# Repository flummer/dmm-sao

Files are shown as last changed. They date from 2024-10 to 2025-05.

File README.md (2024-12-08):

# SAO Digital Multimeter

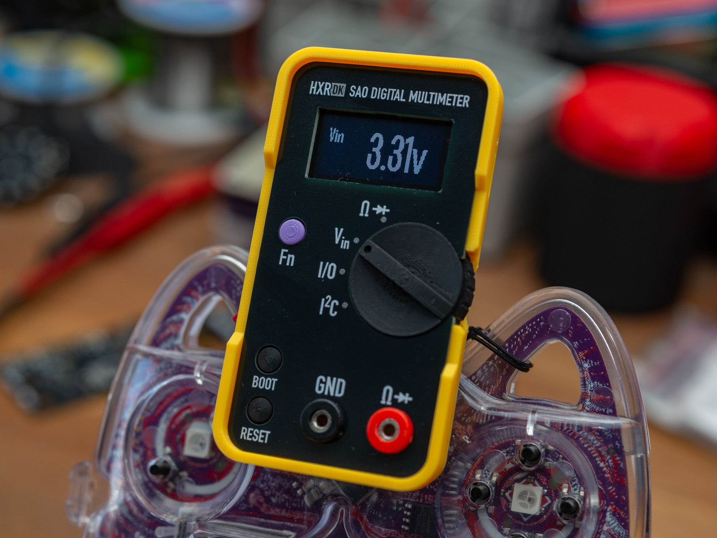
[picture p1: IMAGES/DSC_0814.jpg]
SAO Digital Multimeter


Additional documentation and build log can be found on the [hackaday.io project page for the SAO Digital Multimeter](https://hackaday.io/project/198892-sao-digital-multimeter)

## Features

- Resistance measurement and LED test (including continuity test with a buzzer)
- SAO Input voltage measurement
- SAO GPIO voltage measurement
- I2C info (WIP)

## Firmware

This is designed to run CircuitPython and there is [a custom build](https://github.com/flummer/circuitpython/tree/hxr-sao-dmm) with the needed libraries included, and meaningful pin names for easier development.

A binary build of this is included under `firmware/firmware.uf2` and the application code (`code.py`) and resource files are also in the `firmware` folder.

### Initial programming or CircuitPython updating

- Connect the SAO DMM to a computer usig a USB-C cable and hold down the `Boot` button, when pressing the `Reset` button.
- A new drive should show up called `RPI-RP2`, and you simply copy the `firmware.uf2` file to this drive.
- When the copy is done, the device will disconnect and reboot.
- A new drive will show up named `CIRCUITPY`, and here you need to copy the remaining files in the `firmware` folder to the root folder of the `CIRCUITPY` device.
- The device will not disconnect, but will do one or more reboots, and after that, you are done.

During this, you might be asked or be blocked by your operating system, as sometimes you will need to verify access to new, unknown devices.

## Case and other 3D printed parts

The case and all the button caps, the main knob, and internal spacers to make sure everything sits correctly are designed to be 3D printed with a regular consumer printer. They have been tweaked to be printable with a 0.4mm nozzle, but using a smaller one (eg. 0.2mm) will allow you to use thinner layers, at least in some places, to get a smoother top finnish (top of main knob and top of button caps really benefit from that).

There are also files for a set of 3D printable probes, that are designed to be assembled without any tools, sandwitched around a thin probe wire soldered to a P100-B1 pogo pin for the tip.

There is a `.3mf` file in the `case` folder with a project for BambuLab printers, including 5 plates, one for each color needed.

## Designed in KiCad v8.99 (nightly)

To open the project, you will need to install a recent nightly build (og v9 or newer when released), KiCad v8 or earlier won't open this design directly.

[Electronics schematics as a PDF file](https://github.com/flummer/dmm-sao/blob/main/DMM%20SAO%20Schematics.pdf) is also included for reference.

## License

The hardware design (both electronics and 3D designs) of the `main` branch of this repository is released under the following license:

* the "Creative Commons Attribution-ShareAlike 4.0 International License"
  (CC BY-SA 4.0) full text of this license is included in the LICENSE file
  and a copy can also be found at
  [http://creativecommons.org/licenses/by-sa/4.0/](http://creativecommons.org/licenses/by-sa/4.0/)

The CircuitPython firmware (including the python application code) is released under the MIT license with smaller dependencies under other licenses as detailed in [its LICENSE](https://github.com/flummer/circuitpython/blob/hxr-sao-dmm/LICENSE) and [LICENSE_MicroPython](https://github.com/flummer/circuitpython/blob/hxr-sao-dmm/LICENSE_MicroPython) files.

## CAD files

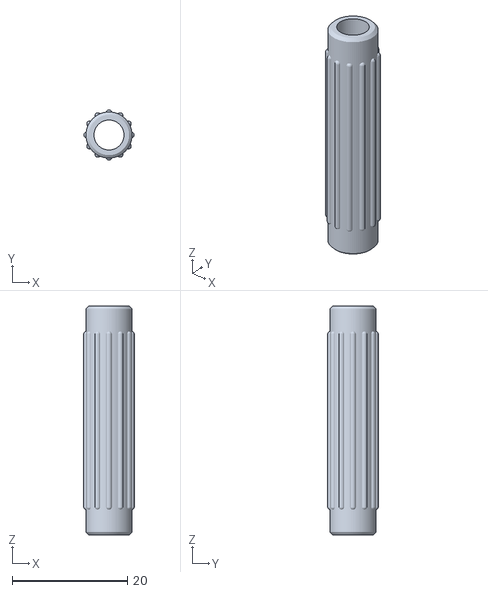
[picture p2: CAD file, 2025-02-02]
case/probe_middle_sleeve_alternative.stl
8.79 x 8.79 x 39.8

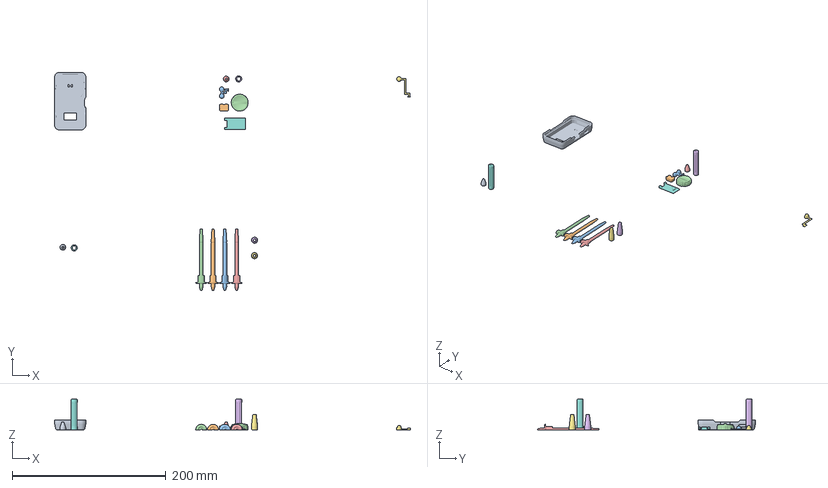
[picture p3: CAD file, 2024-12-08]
case/all_0.4mm_hotend_5_plates_single.3mf
463.8 x 284.3 x 39.8 mm
case_simple.stl
spacer_2.0.stl
buttons_boot_reset_hold_2.0.stl
knob_notches.stl
probe_tip_sleeve.stl x 2
probe_middle_sleeve.stl x 2
button_fn_hold_2.0.stl
probe_half.stl x 4
probe_top_sleeve.stl x 2
screen_support.stl

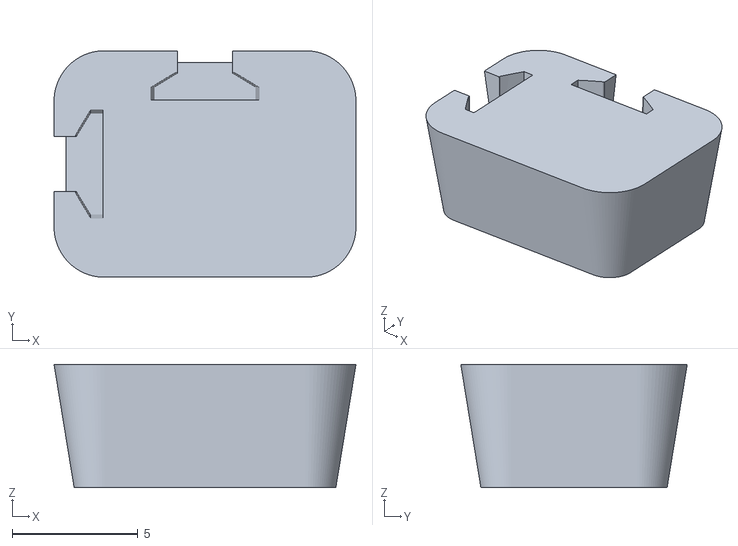
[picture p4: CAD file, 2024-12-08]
case/spacer_2.0.stl
12.0 x 9.00 x 4.90

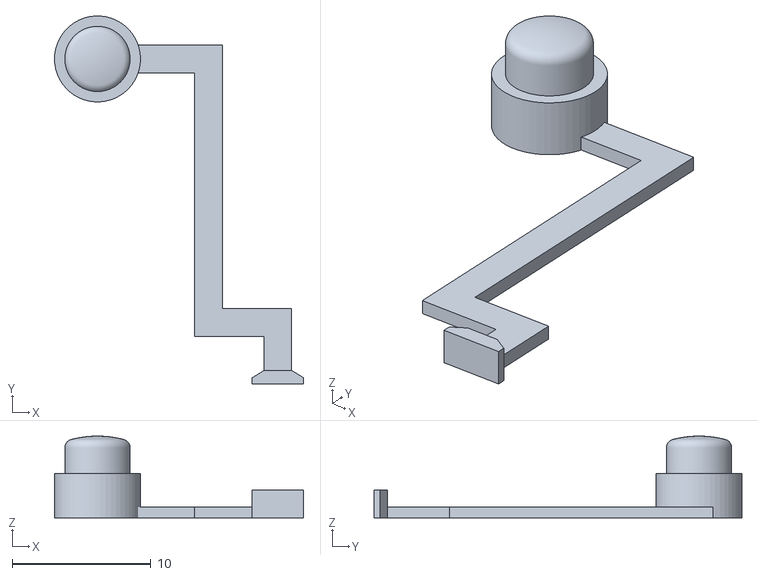
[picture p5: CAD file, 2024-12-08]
case/button_fn_hold_1.5.stl
18.0 x 26.5 x 5.90

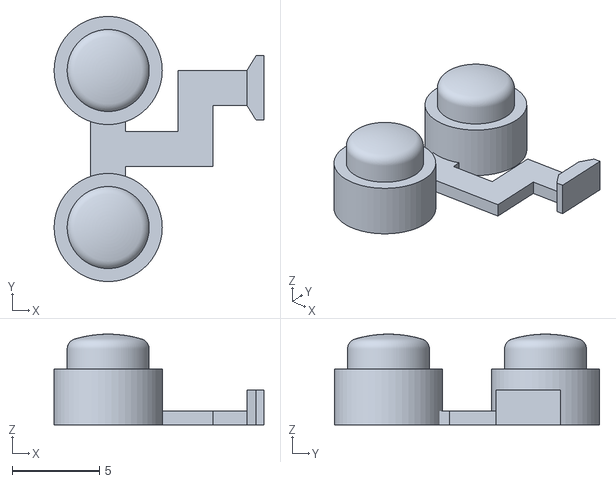
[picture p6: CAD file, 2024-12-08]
case/buttons_boot_reset_hold_1.5.stl
12.0 x 15.2 x 5.20

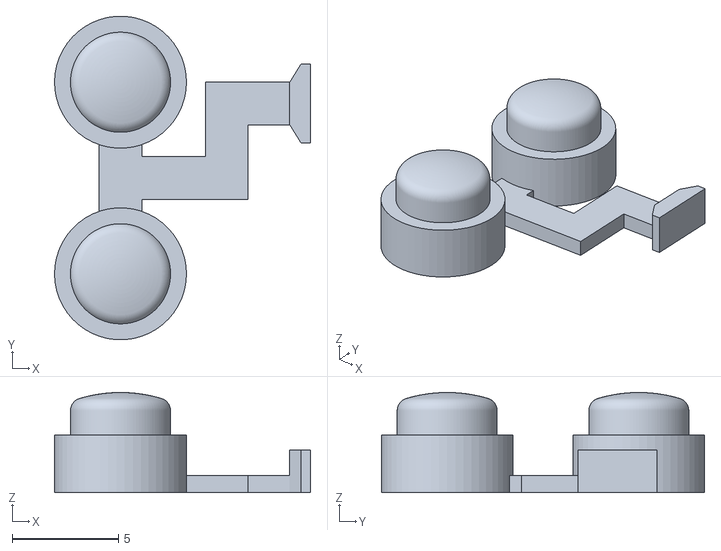
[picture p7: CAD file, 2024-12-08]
case/buttons_boot_reset_hold_2.0.stl
12.0 x 15.2 x 4.70

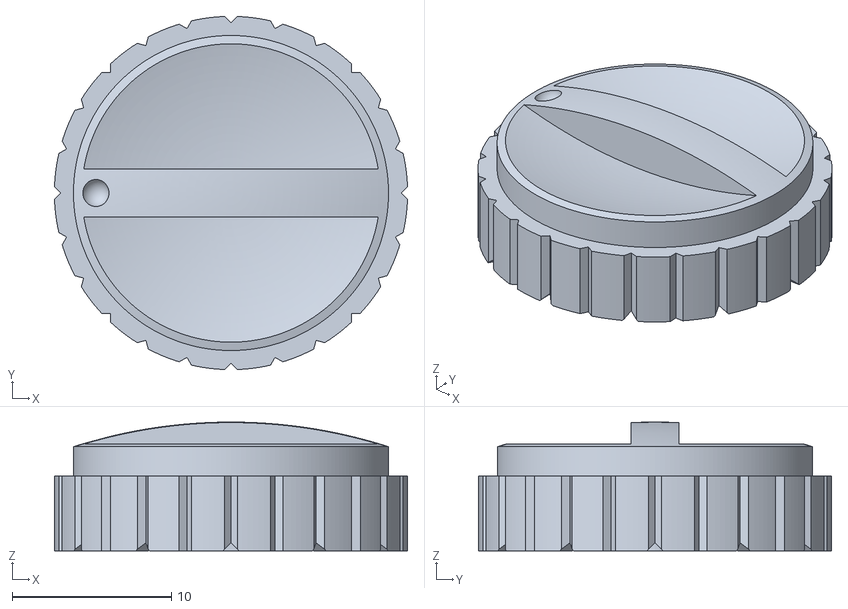
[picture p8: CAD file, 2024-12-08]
case/knob_notches.stl
22.2 x 22.2 x 8.10

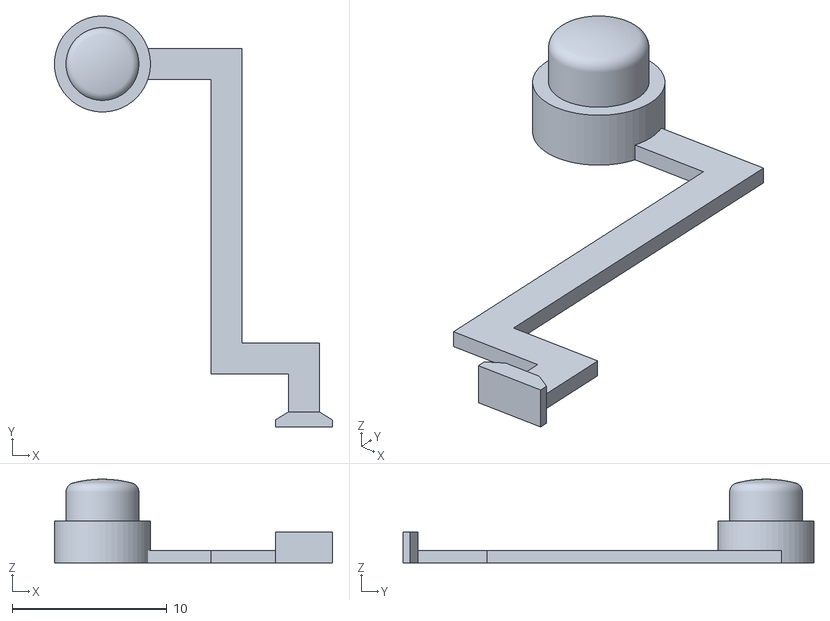
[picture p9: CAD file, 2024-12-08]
case/button_fn_hold_2.0.stl
18.0 x 26.5 x 5.40

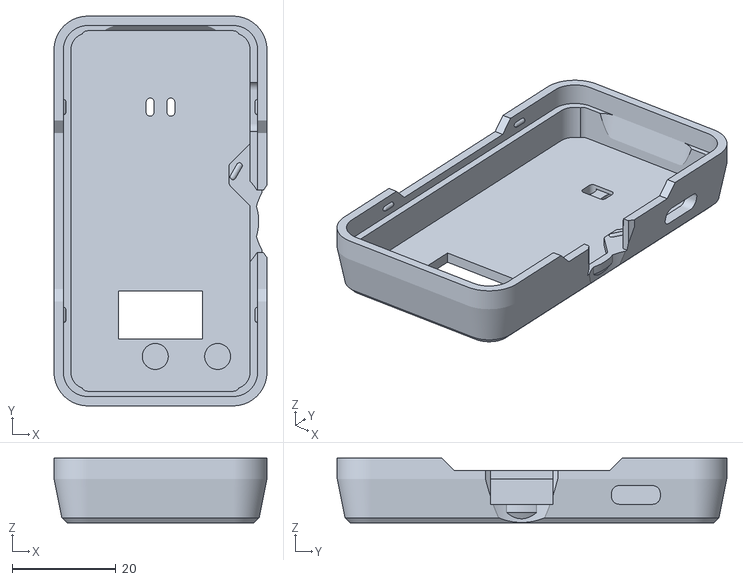
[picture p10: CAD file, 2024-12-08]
case/case_simple.stl
41.0 x 75.0 x 12.5

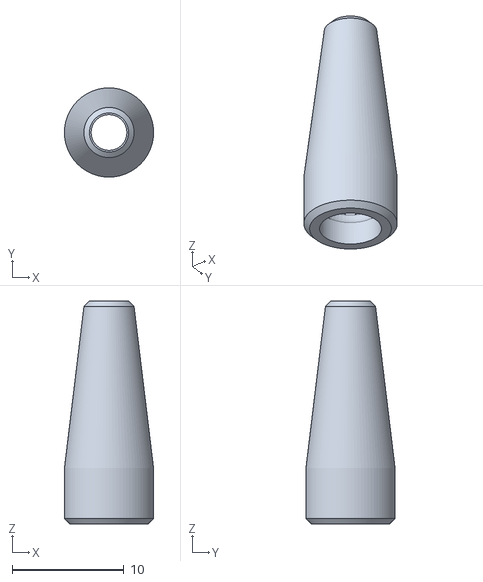
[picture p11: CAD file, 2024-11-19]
case/probe_top_sleeve.stl
8.00 x 8.00 x 20.0

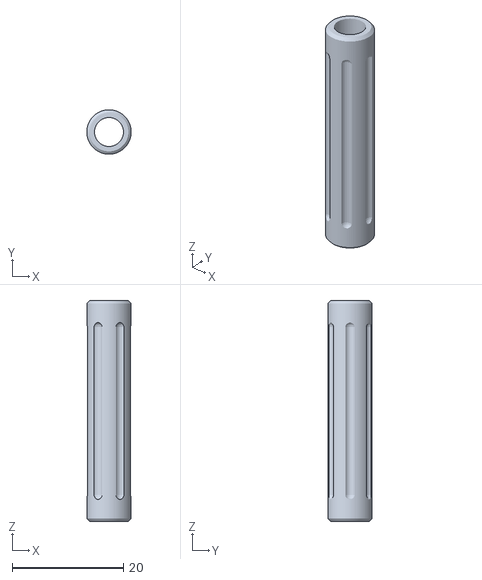
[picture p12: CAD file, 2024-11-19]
case/probe_middle_sleeve.stl
8.00 x 8.00 x 39.8

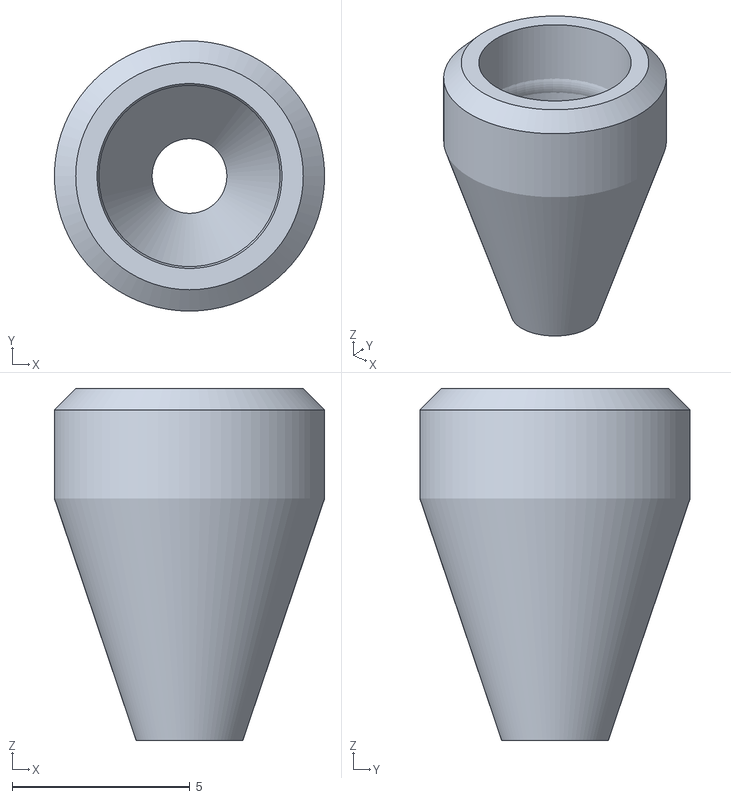
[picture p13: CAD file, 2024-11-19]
case/probe_tip_sleeve.stl
7.60 x 7.60 x 9.90

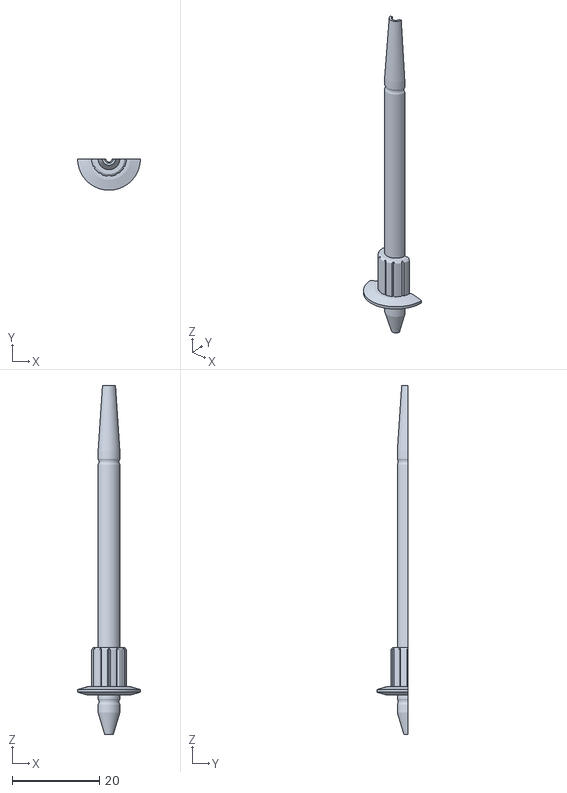
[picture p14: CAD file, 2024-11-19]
case/probe_half.stl
14.4 x 7.20 x 80.0

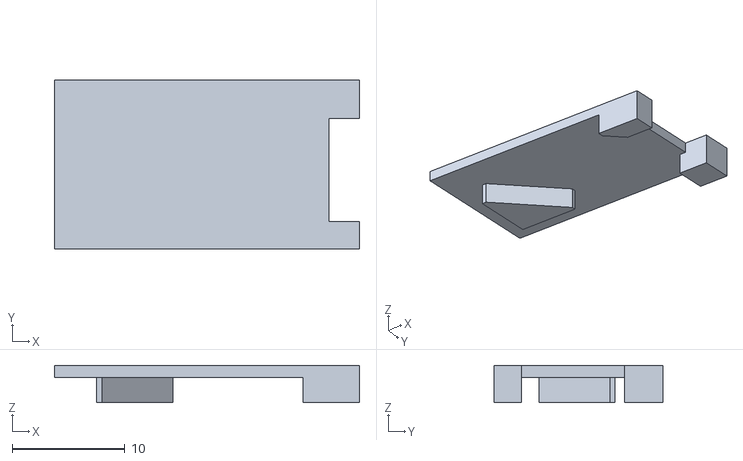
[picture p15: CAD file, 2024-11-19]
case/screen_support.stl
27.0 x 15.0 x 3.30

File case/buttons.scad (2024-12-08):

/* 
 * Button caps for SAO DMM
 *
 * Design: hxr.social/@thomasflummer
 *
 * License: CC-BY-SA
 *
 */

/*
 * Variables for Customizer
 * ==================================================================
 *
 */

// in mm (usually 1.5 og 2.0mm)
ButtonHeight = 2.0;

 
module button(pcb_spacing, pcb_thickness, button_height, extension, diameter, rounding)
{
    difference()
    {
        union()
        {
            minkowski()
            {
                intersection()
                {
                    translate([0, 0, (pcb_spacing + pcb_thickness + extension + 1)/2+(pcb_spacing-1.5-0.5)])
                        cylinder(r = diameter/2 - rounding, h = pcb_spacing + pcb_thickness + extension, center = true, $fn = 100);

                    translate([0, 0, 0])
                        sphere(r = pcb_spacing + pcb_thickness + extension - rounding, $fn = 200);
                }
                
                sphere(r = rounding, $fn = 70);
            }

            translate([0, 0, (pcb_spacing-0.2)/2])
                cylinder(r = diameter/2 + 0.75, h = pcb_spacing, center = true, $fn = 50);

        }
        union()
        {
            translate([0, 0, -10/2 + button_height])
                cube([diameter + 2, diameter + 2, 10], center = true);
        
        }
    }
}

module spacer(pcb_spacing, button_height)
{
    difference()
    {
        union()
        {
            hull()
            {
                for (x = [-1, 1])
                {
                    for (y = [-1, 1])
                    {
                        translate([x*(10/2 - 1), y*(7/2 - 1), pcb_spacing/2])
                            cylinder(r1 = 1.2, r2 = 2, h = pcb_spacing, center = true, $fn = 80);
                    }
                }
            }
        }
        union()
        {
            hull()
            {
                for (x = [-1, 1])
                {
                    for (y = [-1, 1])
                    {
                        translate([x*(7/2 - 1), y*(4/2 - 1), 3/2])
                            cylinder(r = 1.1, h = 3.01, center = true, $fn = 80);
                    }
                }
            }
            
            // side, for boot/reset
            translate([-5, 0, button_height])
            hull()
            {
                translate([0.7, 0, 10/2])
                    cube([0.5, 4, 10], center = true);
                translate([0.7, 0, 10-1/2])
                    cube([0.5, 5, 1], center = true);

                translate([0, 0, 10/2])
                    cube([0.2, 2.2, 10], center = true);
                translate([0, 0, 10-1/2])
                    cube([0.5, 2.5, 1], center = true);
            }

            translate([-6, 0, 10/2 + button_height])
                cube([2, 2.2, 10], center = true);

            // top for Fn
            translate([0, 7/2, button_height])
            rotate(-90, [0, 0, 1])
            hull()
            {
                translate([0.7, 0, 10/2])
                    cube([0.5, 4, 10], center = true);
                translate([0.7, 0, 10-1/2])
                    cube([0.5, 5, 1], center = true);

                translate([0, 0, 10/2])
                    cube([0.2, 2.2, 10], center = true);
                translate([0, 0, 10-1/2])
                    cube([0.5, 2.5, 1], center = true);
            }

            translate([0, 7/2+1, button_height])
            rotate(-90, [0, 0, 1])
            translate([0, 0, 10/2])
                cube([2, 2.2, 10], center = true);

        }        
    }
}

// Black spacer
if(true)
{
    color("#ffcc00")
    spacer(4.9, ButtonHeight);
}

// Purple Fn button
if(true)
{
    color("#9977ff")
    union()
    {
        translate([-13, 26, 0])
            button(4.8, 1.6, ButtonHeight, 1, 4.7, 0.6);

        translate([-13+8/2+1, 26, 0.8/2+ButtonHeight])
            cube([8, 2, 0.8], center = true);

        translate([-5, 26 - 20/2, 0.8/2+ButtonHeight])
            cube([2, 20, 0.8], center = true);

        translate([-5/2, 7, 0.8/2+ButtonHeight])
            cube([5, 2, 0.8], center = true);

        translate([0, 3.5+4.5/2, 0.8/2+ButtonHeight])
            cube([2, 4.5, 0.8], center = true);

        // top for Fn
        translate([0, 7/2, ButtonHeight])
        rotate(-90, [0, 0, 1])
        hull()
        {
            translate([0.7, 0, 2/2])
                cube([0.45, 4-0.3, 2], center = true);

            translate([0, 0, 2/2])
                cube([0.1, 2, 2], center = true);
        }
    }
}

// Black Boot and Reset buttons
if(true)
{
    color("#444444")
    union()
    {
        translate([-13, 1, 0])
            button(4.8, 1.6, ButtonHeight, 0.3, 4.7, 0.6);

        translate([-13, -8, 0])
            button(4.8, 1.6, ButtonHeight, 0.3, 4.7, 0.6);

        translate([-13, -3.5, 0.8/2+ButtonHeight])
            cube([2, 9, 0.8], center = true);

        translate([-13+6/2, -3.5, 0.8/2+ButtonHeight])
            cube([6, 2, 0.8], center = true);

        translate([-13+5, -5.5/2+1, 0.8/2+ButtonHeight])
            cube([2, 5.5, 0.8], center = true);

        translate([-5-4/2, 0, 0.8/2+ButtonHeight])
            cube([4, 2, 0.8], center = true);

        translate([-5, 0, ButtonHeight])
        hull()
        {
            translate([0.7, 0, 2/2])
                cube([0.45, 4-0.3, 2], center = true);

            translate([0, 0, 2/2])
                cube([0.1, 2, 2], center = true);
        }
    }
}

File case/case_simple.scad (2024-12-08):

/* 
 * Case for SAO DMM
 *
 * Design: hxr.social/@thomasflummer
 *
 * License: CC-BY-SA
 *
 */

module case(width, height)
{
    difference()
    {
        union()
        {
            hull()
            {
                for (x = [-1, 1])
                {
                    for (y = [-1, 1])
                    {
                        translate([x*(width/2), y*(height/2), 1 + (8.5 - 1)/2])
                            cylinder(r1 = 3 + 2, r2 = 4.5 + 2, h = 8.5-1, center = true, $fn = 200);

                        translate([x*(width/2), y*(height/2), 2/2])
                            cylinder(r = 3 + 2 - 1, h = 2, center = true, $fn = 200);        
                    }
                }
            }

            hull()
            {
                for (x = [-1, 1])
                {
                    for (y = [-1, 1])
                    {
                        translate([x*(width/2), y*(height/2), 8.5 + 4/2])
                            cylinder(r1 = 4.5 + 2, r2 = 4.5 + 2, h = 4, center = true, $fn = 200);
                    }
                }
            }
            
        }
        union()
        {

            // front plate PCB
            hull()
            {
                for (x = [-1, 1])
                {
                    for (y = [-1, 1])
                    {
                        translate([x*(width/2), y*(height/2), 8.5 + 4/2])
                            cylinder(r = 4.5 + 0.2, h = 4.01, center = true, $fn = 200);
                    }
                }
            }

            // base PCB
            hull()
            {
                for (x = [-1, 1])
                {
                    for (y = [-1, 1])
                    {
                        translate([x*(width/2), y*(height/2), 8.5/2 + 2])
                            cylinder(r = 3 + 0.25, h = 8.51, center = true, $fn = 80);
                    }
                }
            }

            // space for v-score left overs
            hull()
            {
                for (x = [-1, 1])
                {
                    for (y = [-1, 1])
                    {
                        translate([x*(width/2), y*(height/2 - 1.25 + 3 + 0.7), 8.5/2 + 2])
                            cylinder(r = 1 + 0.25, h = 8.51, center = true, $fn = 80);
                    }
                }
            }

            // space for screen flex
            hull()
            {
                for (x = [-1, 1])
                {
                    translate([x*(width/2 - 6), (height/2), 6.5/2 + 2])
                        cylinder(r1 = 3 + 0.25, r2 = 4.5 + 0.2, h = 6.51, center = true, $fn = 80);
                }
            }
            
            
            // side cutoffs
            hull()
            {
                translate([0, 0, 10/2 + 8.5 + 1.6])
                    cube([50, 30, 10], center = true);

                translate([0, 0, 10/2 + 8.5 + 1.6 + 10])
                    cube([50, 50, 10], center = true);
            }
            
            // sao connector
            translate([0, -20, 0])
                cube([16.2, 9.2, 10], center = true);

            // 2mm banana space
            translate([11, -28, 2/2 + 1])
                cylinder(d = 5, h = 2, center = true, $fn = 80);

            translate([-1, -28, 2/2 + 1])
                cylinder(d = 5, h = 2, center = true, $fn = 80);

            // knob
            translate([9, -2, 10/2 + 2 + 1.6])
                cylinder(r = 11.3, h = 10, center = true, $fn = 250);

            translate([9+22-1.6, -2, 10/2 + 2 + 1.6])
                cylinder(r = 11.3, h = 20, center = true, $fn = 250);
            
            translate([9+22-11, -2, 10/2 + 2 + 1.6])
                cube([10, 12, 10], center = true);
                
            // knob notch ball
            if(false)
            {
                translate([9, -2, 3.6-0.3])
                rotate(30, [0, 0, 1])
                translate([10.6, 0, 0])
                    sphere(d = 1.5, $fn = 30);
            }

            // usb connector
            translate([width/2+5, 20, 2 + 1.6 + 3.6/2])
            rotate(90, [0, 0, 1])
            rotate(90, [1, 0, 0])
                hull()
                {
                    for (x = [-1, 1])
                    {
                        for (y = [-1, 1])
                        {
                            translate([x*(9.4/2 - 1.5), y*(3.6/2 - 1.5), 0])
                                cylinder(h = 10, r = 1.5, center = true, $fn = 50);
                        }
                    }
                }

            translate([width/2 + 3 + 1.5 + 0.2 - 5/2, 20, 2 + 1.6 + 3.6/2 + 10/2])
            rotate(90, [0, 0, 1])
            rotate(90, [1, 0, 0])
                hull()
                {
                    for (x = [-1, 1])
                    {
                        for (y = [-1, 1])
                        {
                            translate([x*(9.4/2 - 1.5), y*(13.6/2 - 1.5), 0])
                                cylinder(h = 5, r = 1.5, center = true, $fn = 50);
                        }
                    }
                }

            // SAO Leash mount
            hull()
            {
                for (x = [-1, 1])
                {
                    for (y = [-1, 1])
                    {
                        translate([x*(4/2), y*(2/2) + 20, 2 - 0.75/2])
                            cylinder(d = 1.5, h = 0.751, center = true, $fn = 80);
                    }
                }
            }

            for (x = [-1, 1])
            {
                hull()
                {
                    for (y = [-1, 1])
                    {
                        translate([x*(4/2), y*(2/2) + 20, 2 - 0.5/2])
                            cylinder(d = 1.5, h = 5.51, center = true, $fn = 80);
                    }
                }
            }
    
    
        }        
    }
    
    for (x = [-1, 1])
    {
        for (y = [-1, 1])
        {
            translate([x*(width/2 + 4.5 + 0.1 + 0.1), y*(height/2-11), 8.5 + 1.6 + 0.3])
            hull()
            {
                translate([0, 1, 0])
                    sphere(r = 0.5, $fn = 20);

                translate([0, -1, 0])
                    sphere(r = 0.5, $fn = 20);
            }
        }
    }

    // base for intent notch
    difference()
    {
        hull()
        {
            translate([9 + 5 + 4, -2 + 10.58 + 4, 1 + (3.6 - 1)/2])
                cylinder(r = 0.8, h = 3.6 - 1, center = true, $fn = 050);

            translate([9 + 5, -2 + 10.58, 1 + (3.6 - 1)/2])
                cylinder(r = 0.8, h = 3.6 - 1, center = true, $fn = 150);

            translate([9 + 5, -2 + 7.41, 1 + (3.6 - 1)/2])
                cylinder(r = 0.8, h = 3.6 - 1, center = true, $fn = 150);

            translate([9 + 5 + 4, -2 + 7.41 - 4, 1 + (3.6 - 1)/2])
                cylinder(r = 0.8, h = 3.6 - 1, center = true, $fn = 150);
        }
        
        translate([9-1.7+21, -2 + 9, 3.6/2])
            cube([20, 20, 4], center = true);
    }

    if(true)
    {
        hull()
        {
            translate([9, -2, 3.6-0.2])
            rotate(60, [0, 0, 1])
            translate([12.4, 0, 0])
                sphere(d = 1.2, $fn = 30);

            translate([9, -2, 3.6-0.2])
            rotate(60, [0, 0, 1])
            translate([9.9, 0, 0])
                sphere(d = 1.2, $fn = 30);
        }
    }

    difference()
    {
        // base under knob
        hull()
        {
            translate([9, -2, 2 + (2.6 - 1)/2])
                cylinder(r = 9.9, h = 2.6 - 1, center = true, $fn = 250);

            translate([9, -2, 2/2 + 0.5])
                cylinder(r = 9.9-1, h = 2, center = true, $fn = 150);
        }
        
        translate([9-1.7, -2, 3.6/2])
            cube([20, 20, 4], center = true);
            
        // knob notch ball
        if(false)
        {
            translate([9, -2, 3.6-0.2])
            rotate(30, [0, 0, 1])
            translate([10.4, 0, 0])
                sphere(d = 1.5, $fn = 30);
        }
    }

}

color("#ffcc00")
case(28, 62);

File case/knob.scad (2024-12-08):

/* 
 * Rotary knob for SAO DMM
 *
 * Design: hxr.social/@thomasflummer
 *
 * License: CC-BY-SA
 *
 */

module knob(pcb_spacing, pcb_thickness, extension, diameter, rounding)
{
    difference()
    {
        union()
        {
            translate([0, 0, (pcb_spacing - 0.2)/2])
                cylinder(r = diameter/2 + 1.2, h = pcb_spacing-0.2, center = true, $fn = 200);

            minkowski()
            {
                difference()
                {
                    intersection()
                    {
                        translate([0, 0, (pcb_spacing + pcb_thickness + extension)/2])
                            cylinder(r = diameter/2, h = pcb_spacing + pcb_thickness + extension + 1, center = true, $fn = 200);

                        translate([0, 0, -(pcb_spacing + pcb_thickness + extension)*3])
                            sphere(r = (pcb_spacing + pcb_thickness + extension)*4, $fn = 400);
                    }
                    difference()
                    {
                        translate([0, 0, (pcb_spacing + pcb_thickness + extension)*5-3.7+0.3])
                            sphere(r = (pcb_spacing + pcb_thickness + extension)*4 - rounding, $fn = 400);

                        translate([0, 0, 0])
                            cube([diameter + 2, 3, 25], center = true);

                    }
                }
                //sphere(r = rounding, $fn = 15);
            }
        }
        union()
        {
            // smooth bottom
            translate([0, 0, -3/2])
                cube([diameter + 2, diameter + 2, 3], center = true);

            // cavity for rotary encoder
            translate([0, 0, (3)/2])
                cylinder(r = 9.5, h = 3.1, center = true, $fn = 200);

            // knob indicator indent
            translate([-8.5, 0, 7])
                sphere(d = 1.7, $fn = 100);
                
            // notches on the bottom of the knob
            for (a = [30, 60, 90, 120, 150, 180])
            {
                translate([0, 0, -0.2])
                rotate(a, [0, 0, 1])
                rotate(90, [1, 0, 0])
                rotate(45, [0, 0, 1])
                    cube([1, 1, 30], center = true);
            }

            // notches on teh outside of the knob
            for (a = [0 : 15 : 360])
            {
                translate([0, 0, 0])
                rotate(a, [0, 0, 1])
                translate([11.4, 0, 0])
                rotate(45, [0, 0, 1])
                    cube([1, 1, 30], center = true);
            }

        }
    }
    
    // connection to rotary encoder
    difference()
    {
        union()
        {
            translate([0, 0, (3.2)/2])
                cylinder(d = 4, h = 3.2, center = true, $fn = 50);        
        }
        union()
        {
            translate([0, 3, 5/2])
                cube([3, 3, 5.1], center = true);

            translate([0, -3, 5/2])
                cube([3, 3, 5.1], center = true);
        }
    }
}

/*
color("#222222")
difference()
{
    translate([0, 0, 1.6/2 + 4.9])
        cube([50, 50, 1.6], center = true);
    
    translate([0, 0, 0])
        cylinder(d = 20, h = 20, center = true, $fn = 50);
}
*/

difference()
{
    color("#444444")
    knob(4.9, 1.6, 1.6, 9.9*2, 0.6);
    
    //translate([50/2, 0, 0])
    //    cube([50, 50, 50], center = true);
}

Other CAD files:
case/spacer_1.5.stl
case/probe.scad
case/screen_support.scad
case/spacer.scad

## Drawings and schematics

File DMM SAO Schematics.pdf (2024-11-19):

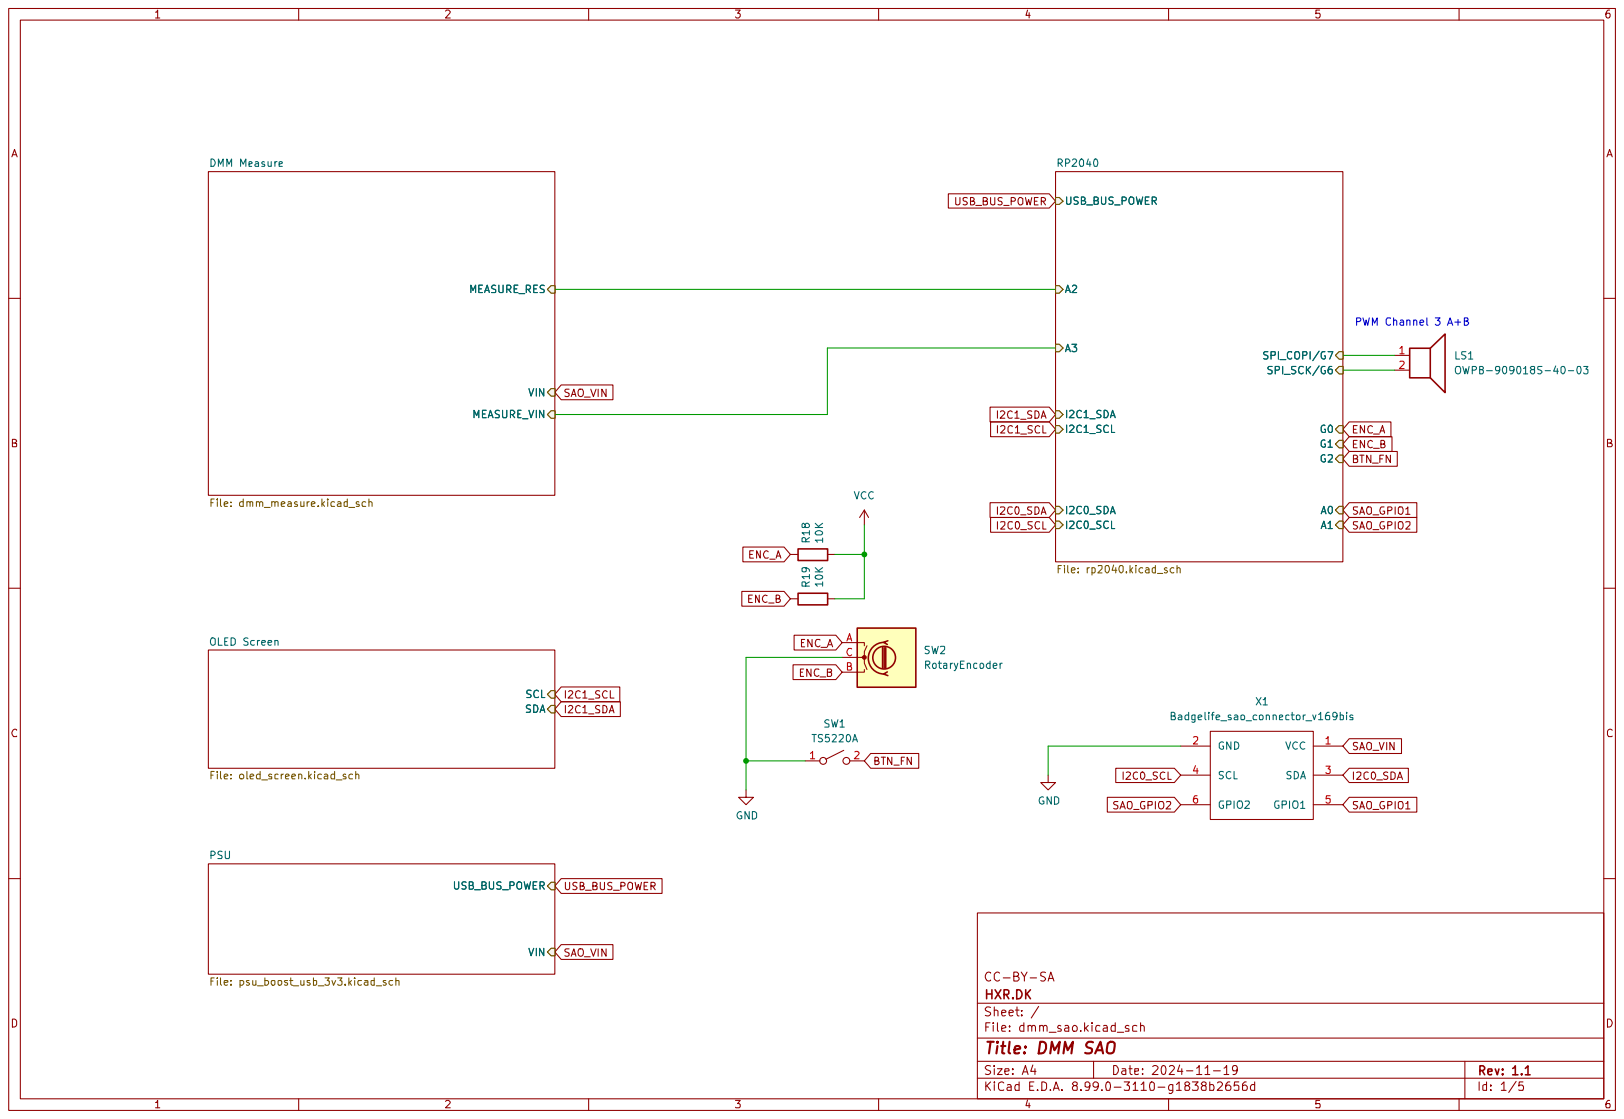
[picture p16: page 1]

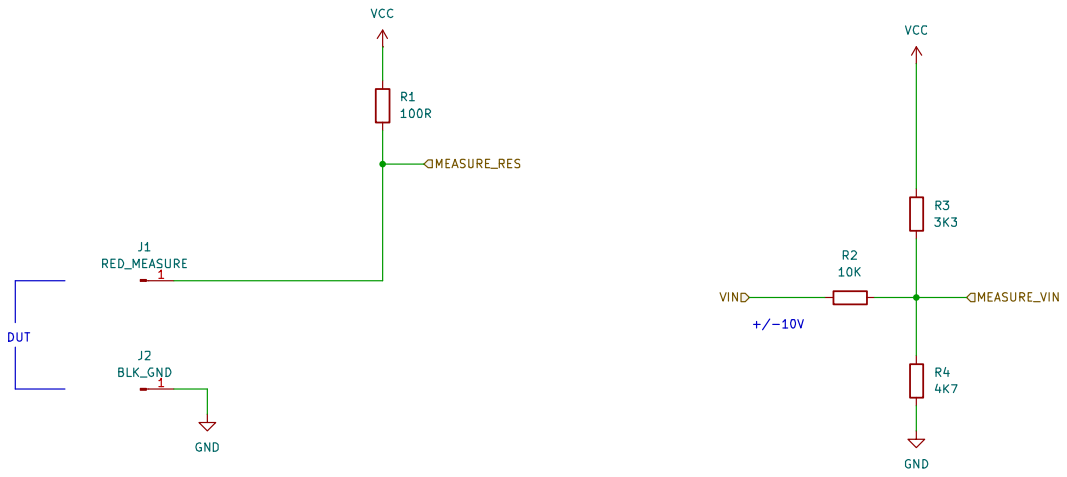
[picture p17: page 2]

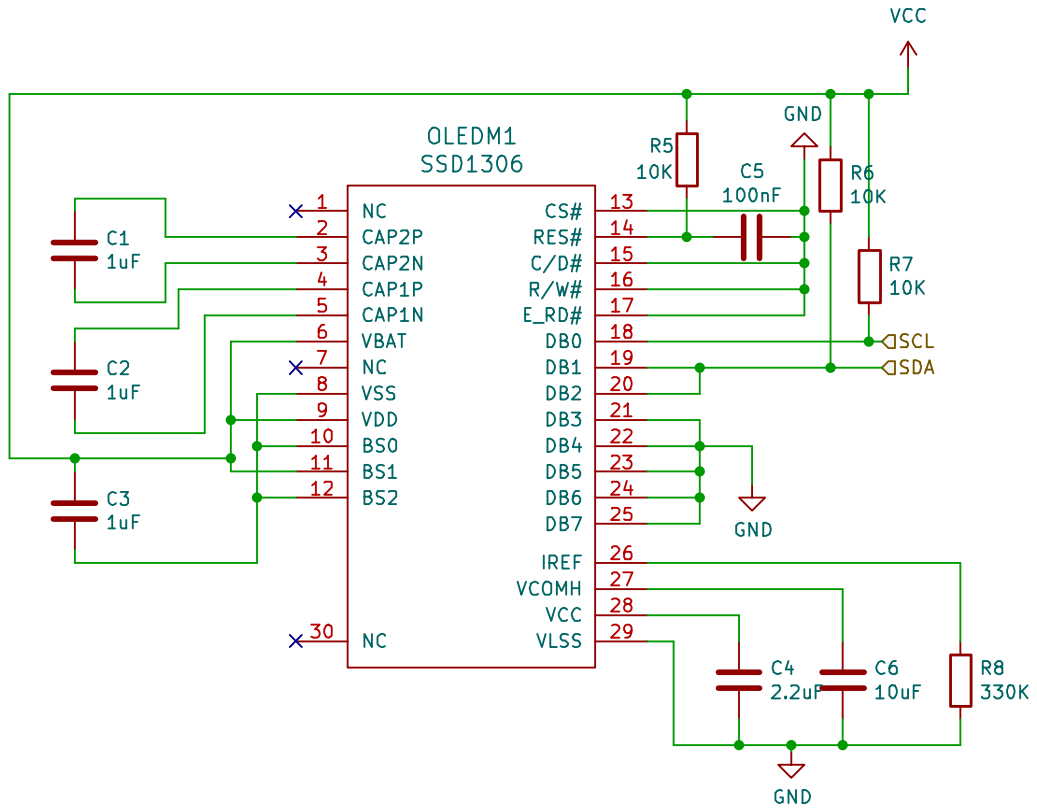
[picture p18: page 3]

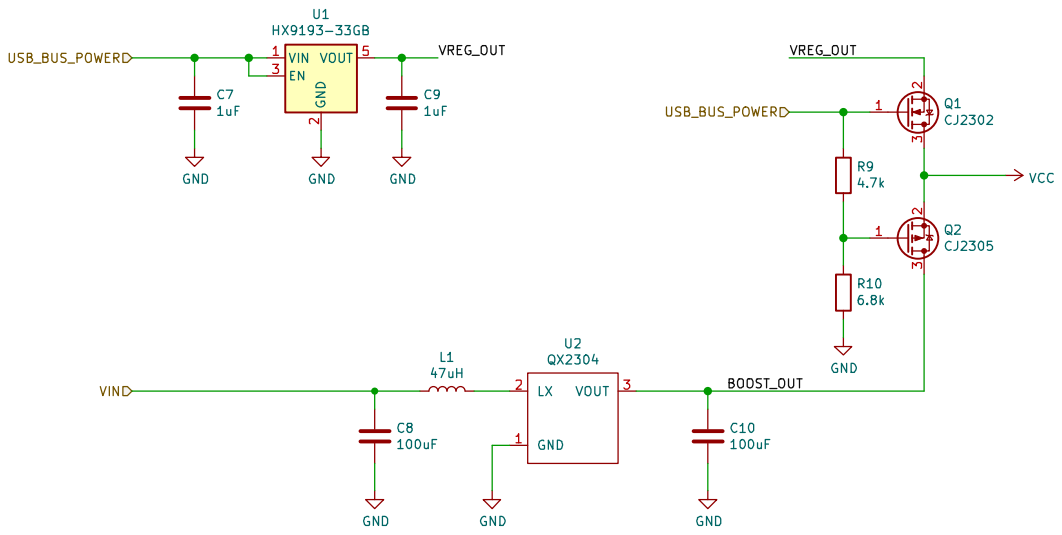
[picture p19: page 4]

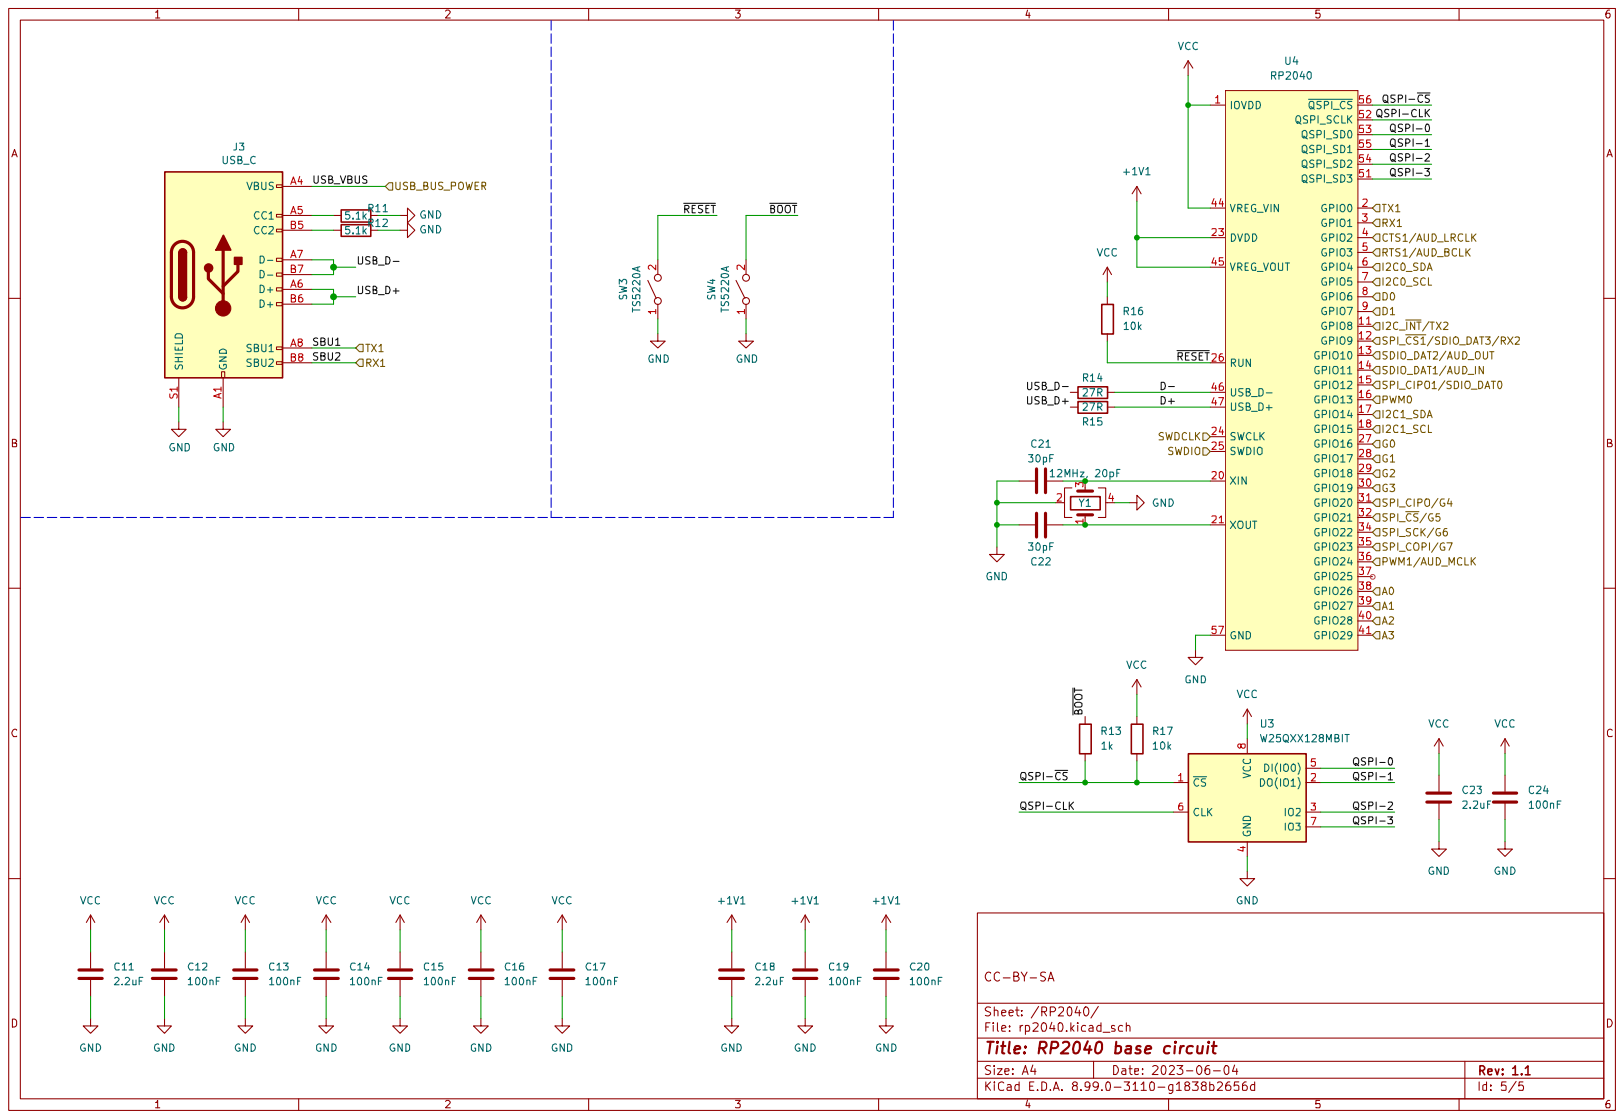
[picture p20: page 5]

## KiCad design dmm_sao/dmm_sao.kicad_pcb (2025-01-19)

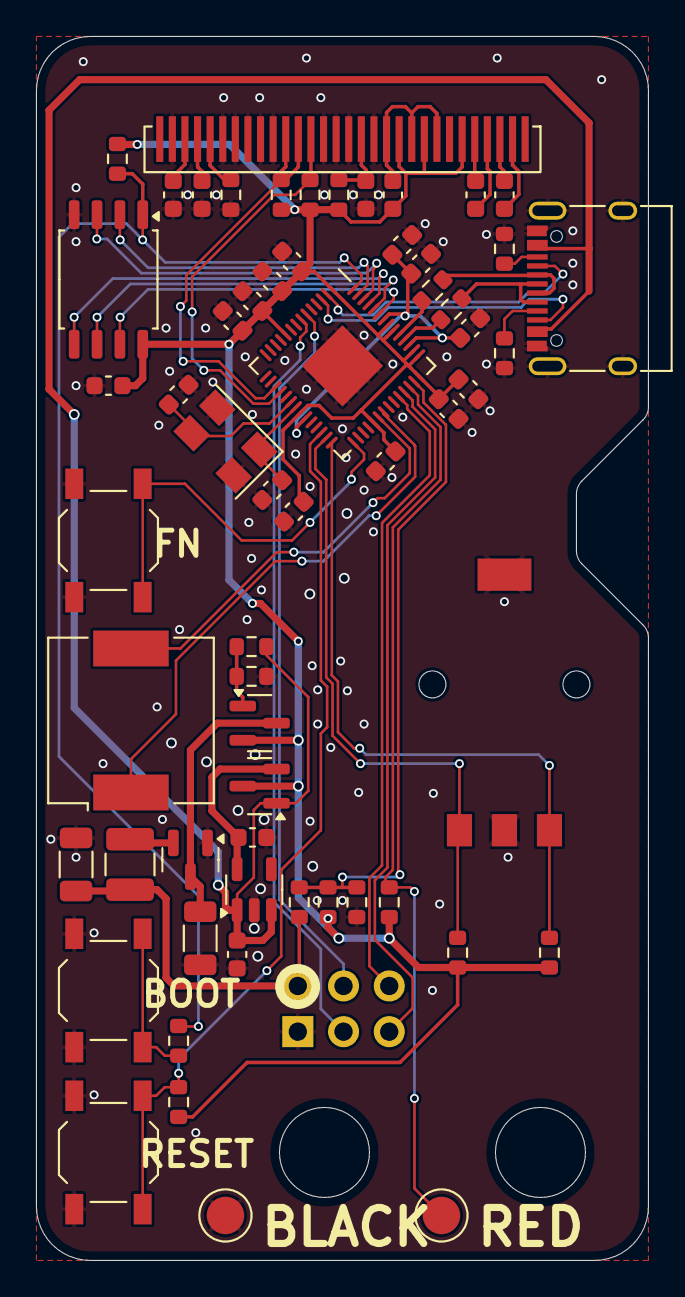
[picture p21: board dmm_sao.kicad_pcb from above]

Board: 2 copper layers, 34.0 x 68.0 mm, 63 parts (0 on the bottom side), 49 nets.

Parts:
C1, C2, C3, C7, C9: 1uF; C_0603_1608Metric
C4, C11, C18, C23: 2.2uF; C_0603_1608Metric
C5, C12, C13, C14, C15, C16, C17, C19, C20, C24: 100nF; C_0603_1608Metric
C6: 10uF; C_0603_1608Metric
C8, C10: 100uF; C_1206_3216Metric
C21, C22: 30pF; C_0603_1608Metric
FRONT: Case
J1: RED_MEASURE; TestPoint_Pad_D2.5mm
J2: BLK_GND; TestPoint_Pad_D2.5mm
J3: USB_C; USB_C_Receptacle_XKB_U262-16XN-4BVC11
L1: 47uH; L_1210_3225Metric
LS1: OWPB-909018S-40-03; Buzzer_CUI_CPT-9019S-SMT
OLEDM1: SSD1306; IROP055-SSD1306Z-PADS-ONLY
Q1: CJ2302; SOT-23
Q2: CJ2305; SOT-23
R1: 100R; R_0603_1608Metric
R2, R5, R6, R7, R18, R19: 10K; R_0603_1608Metric
R3: 3K3; R_0603_1608Metric
R4: 4K7; R_0603_1608Metric
R8: 330K; R_0603_1608Metric
R9: 4.7k; R_0603_1608Metric
R10: 6.8k; R_0603_1608Metric
R11, R12: 5.1k; R_0603_1608Metric
R13: 1k; R_0603_1608Metric
R14, R15: 27R; R_0603_1608Metric
R16, R17: 10k; R_0603_1608Metric
SCREEN_SUPPORT: Case
SW1, SW3, SW4: TS5220A; SW_SPST_TL3342
SW2: RotaryEncoder; EVQ-VV
U1: HX9193-33GB; SOT-23-5
U2: QX2304; SOT-23
U3: W25QXX128MBIT; SOIC-8_5.23x5.23mm_P1.27mm
U4: RP2040; QFN-56_EP_7x7_Pitch0.4mm
X1: Badgelife_sao_connector_v169bis; Badgelife-SAOv169-SAO-2x3
Y1: 12MHz, 20pF; Crystal_SMD_5032-4Pin_5.0x3.2mm

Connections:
+1V1: C18.1, C19.1, C20.1, U4.23 (DVDD), U4.45 (VREG_VOUT), U4.50 (DVDD)
/DMM Measure/MEASURE_RES: J1.1, R1.2, U4.40 (GPIO28)
/DMM Measure/MEASURE_VIN: R2.2, R3.1, R4.1, U4.41 (GPIO29)
/PSU/BOOST_OUT: C10.1, Q2.3 (D), U2.3 (VOUT)
/PSU/VREG_OUT: C9.1, Q1.2 (S), U1.5 (VOUT)
/RP2040/D+: R15.2, U4.47 (USB_D+)
/RP2040/D-: R14.2, U4.46 (USB_D-)
/RP2040/QSPI-0: U3.5 (DI(IO0)), U4.53 (QSPI_SD0)
/RP2040/QSPI-1: U3.2 (DO(IO1)), U4.55 (QSPI_SD1)
/RP2040/QSPI-2: U3.3 (IO2), U4.54 (QSPI_SD2)
/RP2040/QSPI-3: U3.7 (IO3), U4.51 (QSPI_SD3)
/RP2040/QSPI-CLK: U3.6 (CLK), U4.52 (QSPI_SCLK)
/RP2040/QSPI-~CS: R13.2, R17.2, U3.1 (~CS), U4.56 (~QSPI_CS)
/RP2040/SBU1: J3.A8 (SBU1), U4.2 (GPIO0)
/RP2040/SBU2: J3.B8 (SBU2), U4.3 (GPIO1)
/RP2040/SPI_COPI/G7: LS1.1, U4.35 (GPIO23)
/RP2040/SPI_SCK/G6: LS1.2, U4.34 (GPIO22)
/RP2040/USB_D+: J3.A6 (D+), J3.B6 (D+), R15.1
/RP2040/USB_D-: J3.A7 (D-), J3.B7 (D-), R14.1
/RP2040/~BOOT: R13.1, SW4.2 (B)
/RP2040/~RESET: R16.2, SW3.2 (B), U4.26 (RUN)
BTN_FN: SW1.2 (B), U4.29 (GPIO18)
ENC_A: R18.1, SW2.A, U4.27 (GPIO16)
ENC_B: R19.1, SW2.B, U4.28 (GPIO17)
GND: C4.2, C5.1, C6.2, C7.2, C8.2, C9.2, C10.2, C11.2, C12.2, C13.2, C14.2, C15.2, C16.2, C17.2, C18.2, C19.2, C20.2, C21.1, C22.1, C23.2, C24.2, J2.1, J3.A1 (GND), J3.A12 (GND), J3.B1 (GND), J3.B12 (GND), J3.S1 (SHIELD), OLEDM1.13 (CS#), OLEDM1.15 (C/D#), OLEDM1.16 (R/W#), OLEDM1.17 (E_RD#), OLEDM1.21 (DB3), OLEDM1.22 (DB4), OLEDM1.23 (DB5), OLEDM1.24 (DB6), OLEDM1.25 (DB7), OLEDM1.29 (VLSS), R4.2, R8.2, R10.2, R11.1, R12.1, SW1.1 (A), SW2.C, SW3.1 (A), SW4.1 (A), U1.2 (GND), U2.1 (GND), U3.4 (GND), U4.19 (TESTEN), U4.57 (GND), X1.2 (GND), Y1.2, Y1.4
I2C0_SCL: U4.7 (GPIO5), X1.4 (SCL)
I2C0_SDA: U4.6 (GPIO4), X1.3 (SDA)
I2C1_SCL: OLEDM1.18 (DB0), R7.2, U4.18 (GPIO15)
I2C1_SDA: OLEDM1.19 (DB1), OLEDM1.20 (DB2), R6.2, U4.17 (GPIO14)
unnamed: J3.A5 (CC1), R11.2
unnamed: J3.B5 (CC2), R12.2
unnamed: C3.2, OLEDM1.8 (VSS), OLEDM1.10 (BS0), OLEDM1.12 (BS2)
unnamed: C2.2, OLEDM1.5 (CAP1N)
unnamed: C2.1, OLEDM1.4 (CAP1P)
unnamed: C1.2, OLEDM1.3 (CAP2N)
unnamed: C1.1, OLEDM1.2 (CAP2P)
unnamed: OLEDM1.26 (IREF), R8.1
unnamed: C5.2, OLEDM1.14 (RES#), R5.2
unnamed: C4.1, OLEDM1.28 (VCC)
unnamed: C6.1, OLEDM1.27 (VCOMH)
unnamed: Q2.1 (G), R9.2, R10.1
unnamed: L1.2, U2.2 (LX)
unnamed: C21.2, U4.20 (XIN), Y1.3
unnamed: C22.2, U4.21 (XOUT), Y1.1
SAO_GPIO1: U4.38 (GPIO26), X1.5 (GPIO1)
SAO_GPIO2: U4.39 (GPIO27), X1.6 (GPIO2)
SAO_VIN: C8.1, L1.1, R2.1, X1.1 (VCC)
USB_BUS_POWER: C7.1, J3.A4 (VBUS), J3.A9 (VBUS), J3.B4 (VBUS), J3.B9 (VBUS), Q1.1 (G), R9.1, U1.1 (VIN), U1.3 (EN)
VCC: C3.1, C11.1, C12.1, C13.1, C14.1, C15.1, C16.1, C17.1, C23.1, C24.1, OLEDM1.6 (VBAT), OLEDM1.9 (VDD), OLEDM1.11 (BS1), Q1.3 (D), Q2.2 (S), R1.1, R3.2, R5.1, R6.1, R7.1, R16.1, R17.1, R18.2, R19.2, U3.8 (VCC), U4.1 (IOVDD), U4.10 (IOVDD), U4.22 (IOVDD), U4.33 (IOVDD), U4.42 (IOVDD), U4.43 (ADC_AVDD), U4.44 (VREG_VIN), U4.48 (USB_VDD), U4.49 (IOVDD)

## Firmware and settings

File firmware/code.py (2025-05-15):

# This file is part of the SAO DMM project (https://github.com/flummer/dmm-sao)
#
# SPDX-FileCopyrightText: Copyright (c) 2024 Thomas Flummer for HXR.DK
#
# SPDX-License-Identifier: MIT

import board
import busio
import time
import displayio
import adafruit_displayio_ssd1306
import pwmio
import memorymap
from analogio import AnalogIn
from digitalio import DigitalInOut, Direction, Pull
from adafruit_display_text import label
from adafruit_bitmap_font import bitmap_font
from adafruit_progressbar.progressbar import HorizontalProgressBar

# Pin usage:
# -------------------------
# Screen SCL: GPIO15 / DISPLAY_SCL
# Screen SDA: GPIO14 / DISPLAY_SDA
# Buzzer A: GPIO22 / BUZZER_A
# Buzzer B: GPIO23 / BUZZER_B
# Vin Measure: A3 / GPIO29 / MEASURE_VIN
# Res Measure: A2  / GPIO28 / MEASURE_RES
# ENC_A: GPIO16 / ENC_A
# ENC_B: GPIO17 / ENC_B
# Fn: GPIO18 / BUTTON_FN
# SAO SCL: GPIO5 / SAO_SCL
# SAO SDA: GPIO4 / SAO_SDA
# SAO GPIO1: A0 / GPIO26 / SAO_GPIO1
# SAO GPIO2: A1 / GPIO27 / SAO_GPIO2

## Release display, as Circuitpython will be using it during reboot when saving
displayio.release_displays()

# Initialize display I2C
i2c_screen = busio.I2C(board.DISPLAY_SCL, board.DISPLAY_SDA)
display_bus = displayio.I2CDisplay(i2c_screen, device_address=0x3C)
display = adafruit_displayio_ssd1306.SSD1306(display_bus, width=128, height=64, rotation=180)

# Initialize SAO I2C (doesn't work at this stage, as there are no pullups unless connected to a badge)
#i2c_sao = busio.I2C(board.SAO_SCL, board.SAO_SDA)

# Load fonts (need to be on the device flash)
bigfont = bitmap_font.load_font("firecracker40.bdf")
smallfont = bitmap_font.load_font("firecracker16.bdf")

# Setup different pins
gpio1_in = AnalogIn(board.SAO_GPIO1)
gpio2_in = AnalogIn(board.SAO_GPIO2)

res_in = AnalogIn(board.MEASURE_RES)
sao_vin = AnalogIn(board.MEASURE_VIN)

enc_a = DigitalInOut(board.ENC_A)
enc_a.direction = Direction.INPUT
enc_b = DigitalInOut(board.ENC_B)
enc_b.direction = Direction.INPUT

fn = DigitalInOut(board.BUTTON_FN)
fn.direction = Direction.INPUT
fn.pull = Pull.UP

# Configure the two buzzer pins to use a frequency of 1333 Hz, and both channels to off
buzzer = pwmio.PWMOut(board.BUZZER_A, frequency = 1333, duty_cycle = 0)
buzzer_b = pwmio.PWMOut(board.BUZZER_B, frequency = 1333, duty_cycle = 0)

# Helper functions to calculate voltages and resistance from the analog readings using constants matching the resistor dividers in the hardware
def get_voltage(pin):
    return (pin.value * 3.3) / 65536

def get_resistance(pin):
    if pin.value < 65536:
        return -(pin.value * 100) / (pin.value - 65536)
    else:
        return 100000

def get_input_voltage(pin):
    return ((pin.value-32250) * 3.3) / 10642

# Helper function to invert the B channel of the PWM slice used to control the buzzer. When used, the buzzer will be louder.
def rp2040_set_pwm_polarity(sliceNo, channel, invert):
    pwm_csr = memorymap.AddressRange(start = 0x40050000 + 0x14 * sliceNo, length = 0x4)
    pwm_ctrl = int.from_bytes(pwm_csr[0:4], "little")
    if invert:
        pwm_ctrl = pwm_ctrl | 0x1 << (2 + channel)
    else:
        pwm_ctrl = pwm_ctrl & ~(0x1 << (2 + channel))
    pwm_csr[0:4] = pwm_ctrl.to_bytes(4, "little")

# Make the display contexts
logo = displayio.Group()
bitmap = displayio.OnDiskBitmap("/hxrdk.bmp")
tile_grid = displayio.TileGrid(bitmap, pixel_shader=bitmap.pixel_shader)
logo.append(tile_grid)
progressbar = HorizontalProgressBar((0, 63), (display.width, 1), bar_color=0xffffff, fill_color=0x0, border_thickness=0, margin_size=0, value=0)
logo.append(progressbar)
display.root_group = logo

progressbar.value = 5

caution = displayio.Group()
bitmap = displayio.OnDiskBitmap("/caution.bmp")
tile_grid = displayio.TileGrid(bitmap, pixel_shader=bitmap.pixel_shader)
caution.append(tile_grid)

progressbar.value = 10

text = "Caution"
caution_caption = label.Label(smallfont, text=text, color=0xFFFF00, x=40, y=15)
caution.append(caution_caption)

progressbar.value = 15

text = "Read manual"
manual_caption = label.Label(smallfont, text=text, color=0xFFFF00, x=40, y=45)
caution.append(manual_caption)

progressbar.value = 20

# Resistance, LED and Continuity panel
res_panel = displayio.Group()
text = "-"
res_caption = label.Label(smallfont, text=text, color=0xFFFF00, x=0, y=10)
res_panel.append(res_caption)

text = "OL"
res_measurement = label.Label(bigfont, text=text, color=0xFFFF00, x=40, y=32)
res_panel.append(res_measurement)

progressbar.value = 30

# Vin panel
vin_panel = displayio.Group()
text = "Vin"
vin_caption = label.Label(smallfont, text=text, color=0xFFFF00, x=0, y=10)
vin_panel.append(vin_caption)

text = "-"
vin_measurement = label.Label(bigfont, text=text, color=0xFFFF00, x=40, y=32)
vin_panel.append(vin_measurement)

progressbar.value = 40

# I/O panel
io_panel = displayio.Group()
text = "I/O Digital"
io_caption = label.Label(smallfont, text=text, color=0xFFFF00, x=0, y=10)
io_panel.append(io_caption)

text = "GPIO1"
io1_caption = label.Label(smallfont, text=text, color=0xFFFF00, x=0, y=30)
io_panel.append(io1_caption)

text = "GPIO2"
io2_caption = label.Label(smallfont, text=text, color=0xFFFF00, x=0, y=50)
io_panel.append(io2_caption)

progressbar.value = 50

text = ""
io1 = label.Label(smallfont, text=text, color=0xFFFF00, x=60, y=30)
io_panel.append(io1)

text = ""
io2 = label.Label(smallfont, text=text, color=0xFFFF00, x=60, y=50)
io_panel.append(io2)

progressbar.value = 60

# I2C panel
i2c_panel = displayio.Group()
text = "I2C"
i2c_caption = label.Label(smallfont, text=text, color=0xFFFF00, x=0, y=10)
i2c_panel.append(i2c_caption)
text = ""
i2c_output1 = label.Label(smallfont, text=text, color=0xFFFF00, x=0, y=30)
i2c_panel.append(i2c_output1)
text = ""
i2c_output2 = label.Label(smallfont, text=text, color=0xFFFF00, x=0, y=50)
i2c_panel.append(i2c_output2)

progressbar.value = 70

# Pre rendering text strings (while showing logo)
res_caption.hidden = True
res_caption.text = "LED"
res_caption.text = "Cont."
res_caption.text = "Cont. L"
res_caption.text = ""
res_caption.hidden = False

progressbar.value = 80

io_caption.hidden = True
io_caption.text = "I/O Analog"
io_caption.text = ""
io_caption.hidden = False

progressbar.value = 85

i2c_caption.hidden = True
i2c_caption.text = "I2C Scanning..."
i2c_caption.text = ""
i2c_caption.hidden = False

progressbar.value = 90

caution_caption.text = "Achtung!"
manual_caption.text = "Handbuch lesen"

progressbar.value = 94

caution_caption.text = "Advarsel!"
manual_caption.text = "Læs vejledning"

progressbar.value = 98

caution_caption.text = "Caution!"
manual_caption.text = "Read manual"

progressbar.value = 100

# Switch to showing caution in EN, DE, DA (cycles until Fn pressed)
display.root_group = caution
caution_sequence = 0

while fn.value:
    if caution_sequence < 30:
        caution_caption.text = "Caution!"
        manual_caption.text = "Read manual"
    elif caution_sequence < 60:
        caution_caption.text = "Achtung!"
        manual_caption.text = "Handbuch lesen"
    else:
        caution_caption.text = "Advarsel!"
        manual_caption.text = "Læs vejledning"

    if caution_sequence > 90:
        caution_sequence = 0

    caution_sequence += 1
    time.sleep(0.05)

main_mode = 0
res_mode = 1
io_mode = 1
i2c_mode = 1

# Main program loop
while True:
    # Handle main mode change and switch to the correct panel (displayio root_group)
    if (enc_a.value & enc_b.value) and main_mode != 1: # Resistance and LED mode
        main_mode = 1
        display.root_group = res_panel
    elif (enc_a.value & (not enc_b.value)) and main_mode != 2: # Vin reading mode
        main_mode = 2
        display.root_group = vin_panel
    elif ((not enc_a.value) & (not enc_b.value)) and main_mode != 3: # GPIO mode
        main_mode = 3
        display.root_group = io_panel
    elif ((not enc_a.value) & enc_b.value) and main_mode != 4: # I2C mode (WIP)
        main_mode = 4
        display.root_group = i2c_panel

    # Update measurement value and handle submode changes
    if main_mode == 1: # Resistance and LED mode
        if res_mode == 1: # Resistance measurement sub mode
            res_caption.text = "Ohm"
            if get_resistance(res_in) > 20000:
                res_measurement.text = "OL"
            elif get_resistance(res_in) > 800:
                res_measurement.text = "%0.1f k" % (get_resistance(res_in)/1000)
            else:
                res_measurement.text = "%0.0f" % (get_resistance(res_in))
        elif res_mode == 2: # LED Test sub mode
            res_caption.text = "LED"
            if get_voltage(res_in) > 3.25:
                res_measurement.text = "OL"
            else:
                res_measurement.text = "%0.2fv" % (get_voltage(res_in))
        elif res_mode == 3: # Continuity sub mode
            res_caption.text = "Cont."
            if get_resistance(res_in) > 20000:
                res_measurement.text = "OL"
            elif get_resistance(res_in) > 800:
                res_measurement.text = "%0.1f k" % (get_resistance(res_in)/1000)
            else:
                res_measurement.text = "%0.0f" % (get_resistance(res_in))
            if get_resistance(res_in) < 50:
                buzzer.duty_cycle = 32000
                rp2040_set_pwm_polarity(3, 1, True)
                buzzer_b.duty_cycle = 32000
            else:
                buzzer.duty_cycle = 0
                rp2040_set_pwm_polarity(3, 1, False)
                buzzer_b.duty_cycle = 0
        elif res_mode == 4: # Continuity with less volumen on the buzzer sub mode
            res_caption.text = "Cont. L"
            if get_resistance(res_in) > 20000:
                res_measurement.text = "OL"
            elif get_resistance(res_in) > 800:
                res_measurement.text = "%0.1f k" % (get_resistance(res_in)/1000)
            else:
                res_measurement.text = "%0.0f" % (get_resistance(res_in))
            if get_resistance(res_in) < 50:
                buzzer.duty_cycle = 32000
            else:
                buzzer.duty_cycle = 0
                buzzer_b.duty_cycle = 0

        if not fn.value:
            res_mode += 1
            if res_mode > 4:
                res_mode = 1
            time.sleep(0.2)

    elif main_mode == 2: # Vin reading mode
        vin_caption.text = "Vin"
        vin_measurement.text = "%0.2fv" % (get_input_voltage(sao_vin))

    elif main_mode == 3: # GPIO mode
        if io_mode == 1: # Digital view sub mode
            io_caption.text = "I/O Digital"
            if get_voltage(gpio1_in) > 2.00:
                io1.text = "HIGH"
            else:
                io1.text = "LOW"
            if get_voltage(gpio2_in) > 2.00:
                io2.text = "HIGH"
            else:
                io2.text = "LOW"
        elif io_mode == 2: # Analog view sub mode
            io_caption.text = "I/O Analog"
            io1.text = "%0.2fv" % (get_voltage(gpio1_in))
            io2.text = "%0.2fv" % (get_voltage(gpio2_in))

        if not fn.value:
            io_mode += 1
            if io_mode > 2:
                io_mode = 1
            time.sleep(0.2)

    elif main_mode == 4: # I2C mode (WIP)
        if i2c_mode > 5:
            # scan
            i2c_caption.text = "I2C Scanning..."

            found_count = 0
            try:
                sao_bus = busio.I2C(board.SAO_SCL, board.SAO_SDA)
                while not sao_bus.try_lock():
                    pass

                i2c_output1.text = ""
                i2c_output2.text = ""

                print("Scanning SAO I2C bus:")
                for device_address in sao_bus.scan():
                    if found_count < 4:
                        i2c_output1.text = i2c_output1.text + hex(device_address) + "  "
                    elif found_count < 8:
                        i2c_output2.text = i2c_output2.text + hex(device_address) + "  "
                    print("Found:", hex(device_address))
                    found_count += 1

                sao_bus.unlock()
                sao_bus.deinit()
                if found_count > 0:
                    i2c_caption.text = "I2C Found:"
                else:
                    i2c_caption.text = "I2C None found!"
            except Exception as e:
                    i2c_caption.text = "I2C Error:"
                    i2c_output1.text = "Got exception"
                    i2c_output2.text = "Check wiring"
                    print("Exeption: ", e)

            time.sleep(2)

            while fn.value:
                time.sleep(0.05)

            i2c_output1.text = ""
            i2c_output2.text = ""
            i2c_mode = 1
        else:
            # sniff
            i2c_caption.text = "I2C"
            i2c_output1.text = "Hold Fn to start scan"
            i2c_output2.text = ""

        if not fn.value:
            i2c_mode += 1
            time.sleep(0.2)
        else:
            i2c_mode = 1

    time.sleep(0.05)

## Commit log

2024-10-22 Added 3D printed parts
    [button_fn_hold.stl, buttons.scad, buttons_boot_reset_hold.stl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]
2024-11-19 Moved buzzer to base board
    Also:
    - Moved a few parts to make space for the buzzer
    - Connected the buzzer in a push/pull setup for better volume
    - Changed the edgecut a little, to have better space for knob intent mechanism in case
    - Tweaked pads for spring loaded pins to match manufacturer suggestion
    - Made the paste for the display connector 10% smaller
    [dmm_sao-B_Cu.gbl, dmm_sao-B_Mask.gbs, dmm_sao-B_Paste.gbp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]
2024-11-19 Added 1x5 panel of the base board
    [panel_1x5-B_Cu.gbl, panel_1x5-B_Mask.gbs, panel_1x5-B_Paste.gbp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]
2024-11-19 Updated 3D print files to match v1.1
    [button_fn_hold.stl, buttons.scad, buttons_boot_reset_hold.stl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]
2024-11-19 Added 3D printable mini probe handle
    [probe.scad, probe_half.stl, probe_middle_sleeve.stl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]
2024-12-02 Updated case to use 3D printed knob intent
    Eliminate need for steel ball
    Also added a little extra space for v-score left overs, when using panelized base PCB
    [case_simple.scad, case_simple.stl]
2024-12-08 Updated 3D printed parts to better work with 0.4mm nozzle
    Also changed button caps to support tactile switches that are 2.0 mm high in addition to those that are 1.5 mm.
    [button_fn_hold.stl, button_fn_hold_1.5.stl, button_fn_hold_2.0.stl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]
2024-12-08 Added printer project with slicer settings for 0.4mm nozzle on Bambu Lab printers
    [all_0.4mm_hotend_5_plates_single.3mf]
2025-01-19 Added logos and adjusted panel tooling holes
    Tool holes changed to be 1.152mm diameter, following JLCPCB assembly spec
    versions bumped to 1.2
    [dmm_sao-B_Cu.gbl, dmm_sao-B_Mask.gbs, dmm_sao-B_Paste.gbp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]
2025-02-02 Added alternative design for the probe middle sleeve
    This is an attempts to improve the print performance on some printers, mainly limiting need for retraction during infill printing
    [probe.scad, probe_middle_sleeve_alternative.stl]
2025-05-15 Updated CircuitPython firmware image to 9.2.7
